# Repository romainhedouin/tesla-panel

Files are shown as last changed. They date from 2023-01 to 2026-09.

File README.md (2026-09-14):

# tesla-panel

Pi-side receiver for the 64×32 RGB LED matrix mounted in the car. Listens
over Bluetooth RFCOMM for commands from the
[TeslaLED](https://github.com/romainhedouin/TeslaLED) Android app and drives
the panel via [rpi-rgb-led-matrix](rpi-rgb-led-matrix/)'s Python bindings.

`rpi-rgb-led-matrix/` is a git submodule pointing straight at
[hzeller/rpi-rgb-led-matrix](https://github.com/hzeller/rpi-rgb-led-matrix)
(no local patches to carry - if that ever changes, fork it first rather
than patching the submodule in place). Clone this repo with `git clone
--recurse-submodules`, or run `git submodule update --init` afterwards if
you already cloned without it - `deploy.sh` needs it checked out locally
to have anything to rsync to the Pi.

`bt_server.py` is the entry point, wiring together `protocol.py` (the wire
protocol - hardware/transport agnostic, covered by `tests/`), `panel.py`
(the RGBMatrix hardware wrapper) and `bt_profile.py` (BlueZ D-Bus service
registration).

`esp32/` is an in-progress port to run instead of the Pi - see its own
README for status (compile-verified only, no hardware yet).

There is no CI/CD deploying to the Pi itself: `./deploy.sh` copies these files
onto the Pi's home directory (`/home/pi/`) by hand and restarts the systemd
service, but nothing runs that automatically - **a protocol or behavior
change isn't live until you actually run `./deploy.sh`**, and nothing checks
that the Pi is still in sync with what's committed here. `tests/` (`python3
-m pytest tests/`) only exercises `protocol.py`, so it catches wire-format
regressions but nothing hardware- or Bluetooth-related.

## Bill of materials

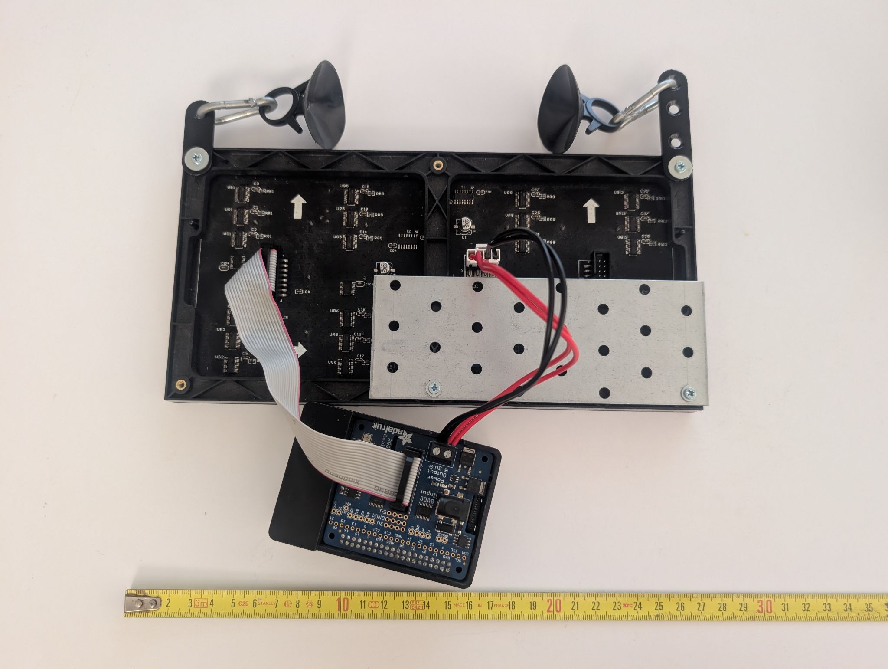
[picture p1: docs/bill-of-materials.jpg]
Panel back, mounting brackets, and HAT


- P4 indoor full-color RGB LED matrix module
  - [Reference photo](https://ae-pic-a1.aliexpress-media.com/kf/HTB1wbN2NVXXXXcDXVXXq6xXFXXX2.jpg) of the one used - no longer listed on AliExpress
  - [This listing](https://fr.aliexpress.com/i/32250605175.html?gatewayAdapt=glo2fra) looks similar but is unverified
- Raspberry Pi 3B+
  - A more recent Pi also works, but draws more power - a small fan may become necessary
- [Adafruit HUB75 HAT](https://www.amazon.fr/dp/B00SK69C6E?ref=ppx_yo2ov_dt_b_fed_asin_title)
- [Raspberry Pi 3/3B+ case](https://www.amazon.fr/dp/B09H6KR3JP?ref=ppx_yo2ov_dt_b_fed_asin_title)
  - Had to file off the plastic cover latches to fit the HAT
- [5.5x2.1mm power cable for the HAT](https://www.amazon.fr/dp/B07KFTPF4C?ref=ppx_yo2ov_dt_b_fed_asin_title)
  - Downsides: thin (22 AWG) and long (2m) - thinner/longer cables drop more
    voltage under load, risking under-voltage and visible brightness
    variability. Prefer shorter, thicker cables.
  - If buying today, would try [this one](https://www.amazon.fr/dp/B0FPKWNFLN/ref=sspa_dk_detail_5) instead - still 22 AWG and half the length, which is plenty
- Micro-USB cable for the Pi (USB-C on more recent models)
- M3 screws + washers
- Mounting brackets - the Tesla Model 3's rear window is laterally sloped
  - 2-hole bracket, 2.5cm between the external holes
  - 4-hole bracket, 4.5cm between the external holes
- 2 small carabiners, attached to the mounting brackets
- 2 small suction cups with a loop, attached to the carabiners
- 2-4 magnets, super-glued to the bottom of the Pi case
  - Mount onto the metal sheet below
- 6x16cm metal sheet with holes
  - Unclear original purpose - used here as an anchor point for the magnets
- A soldering iron, to solder the HAT onto the Pi
  - Easy job, just make sure to solder it the right way around or you'll
    have the delightful pleasure of learning to unsolder and re-solder all
    40 tiny little pins... ask how I know...

## Raspberry Pi OS install

Only needed once, on a fresh/replacement SD card, before `pi_side_install.sh`.
Use [Raspberry Pi Imager](https://www.raspberrypi.com/software/):

1. Choose **Raspberry Pi OS Lite (64-bit)** as the OS.
2. Choose the SD card as the storage device - **be very careful you've
   selected the right one**, this erases it.
3. Follow the app's setup prompts (hostname, user, SSH, WiFi, locale) and
   write.

## Wire protocol

`bt_server.py` speaks a length-prefixed binary protocol, matched byte-for-byte
by the Android app's `BluetoothClient`/`AGENTS.md`:

```
[1 byte command type][4 bytes big-endian payload length][payload]
```

followed by a response in the same shape, mirrored - `[1 byte status][4
bytes big-endian message length][message, UTF-8]`. `0x00` is OK (message
normally empty); anything else is an error, with the message carrying the
Pi's own explanation of what went wrong - the Android app surfaces that
text directly (e.g. as an "ERROR: ..." toast) instead of guessing at a
generic failure reason. Command types (kept in sync with the Android app's
constants of the same name):

| Command | Value | Payload |
|---|---|---|
| `COMMAND_IMAGE` | 0 | a 64×32 P6 PPM frame |
| `COMMAND_KILL` | 2 | none - clears the panel |
| `COMMAND_SET_BRIGHTNESS`  | 3 | 1 byte, 1-100 |

RFCOMM is a reliable ordered stream, so the length prefix is all that's
needed to find message boundaries - no sentinel value, no per-chunk acks.

Updates are flicker-free because `panel.py` creates the matrix and its
canvas once at startup and reuses them for the whole process - each command
does an atomic `SwapOnVSync` onto that same canvas, never a process
kill/respawn.

## Bluetooth service registration

`bt_profile.py` registers the RFCOMM service with BlueZ over D-Bus
(`org.bluez.ProfileManager1.RegisterProfile`) instead of PyBluez's
`advertise_service()` - see that file's module docstring for the full
reasoning. Short version: current BlueZ (5.82+, what Debian 13/trixie ships)
removed the legacy `/var/run/sdp` socket interface `advertise_service()`
(and `sdptool`) depend on, so both fail outright on this OS; and it has to
be a real SDP record, not a shortcut around one, because the Android app
connects via `createRfcommSocketToServiceRecord(UUID)`, which looks up the
RFCOMM channel through an actual SDP query at connect time. This also means
BlueZ owns the listening socket - it hands our exported `Profile1` an
already-connected fd per connection, so there's no `listen()`/`accept()`
anywhere in this codebase. Needs `python3-dbus` and `python3-gi` (installed
by `pi_side_install.sh`).

## Deployment

- Three systemd units (`conf/teslabot*.service`), each supervised
  independently via `Restart=always`:
  - `teslabot.service` runs `bt_server.py`.
  - `teslabot-agent.service` keeps a pairing agent
    (`bt-agent -c NoInputNoOutput`) registered.
  - `teslabot-discoverable.service` (a oneshot) powers Bluetooth on and makes
    it discoverable at boot; `/etc/bluetooth/main.conf`'s `DiscoverableTimeout
    = 0` (set by `pi_side_install.sh`) is what makes that stick instead of
    reverting after BlueZ's default 180s.
- Pairing a new phone with the Pi silently fails (no error anywhere, not even
  in `bluetoothctl paired-devices`) unless that pairing agent is running -
  if pairing won't complete, check `systemctl status teslabot-agent` before
  suspecting anything else.
- The Pi's Bluetooth MAC is hardcoded on the Android side
  (`BluetoothClient.findDevice()`); replacing the Pi means updating that
  constant and rebuilding the app.
- On a fresh Pi: `./deploy.sh` from this repo copies it onto the Pi, then
  `ssh teslapi` and run `./pi_side_install.sh` there (packages, compiling
  `rpi-rgb-led-matrix` and its Python bindings, installing the systemd units).
  Safe to re-run - most of its steps are no-ops if already done.
- After that first install, `./deploy.sh` alone is enough for routine code
  changes: it copies the repo over and restarts `teslabot.service`, so the
  new code is live immediately - no manual ssh/restart step needed.

## Troubleshooting

- **Colored static/noise instead of the actual image** is a GPIO-timing or
  wiring issue, not a protocol/software bug - reproduce it with the LED
  matrix library's own test patterns (`rpi-rgb-led-matrix/examples-api-use`)
  with no Bluetooth involved at all before looking anywhere else.
- **Pairing never completes**: see the pairing-agent note above.
- **Panel doesn't update / commands seem to hang**: check `bt_server.log` in
  `/home/pi/` and `journalctl -u teslabot` - a command whose handler raises
  gets logged and answered with an error status rather than silently
  dropped, so a hang usually means the client never got as far as sending
  the header/payload, not a wedged server.

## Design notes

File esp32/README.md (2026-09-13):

# ESP32 firmware (in progress)

Alternative to the Raspberry Pi, targeting the [HUB75 adapter for
ESP32-DevKitC V4 / ESP32-S3 DevKitC-1](https://www.amazon.fr/dp/B0FVGCF1RW).
Written and compile-verified with [PlatformIO](https://platformio.org/)
(`pip install platformio`) without the physical board in hand - `pio run`
only compiles/links, it doesn't need real hardware. **Nothing here has
been flashed to or tested on real hardware yet.**

## Why two environments

That adapter board is designed to take either dev board, and the two are
not interchangeable for our purposes: the original ESP32 has classic
Bluetooth (BR/EDR), the S3 dropped it entirely (BLE only). That's a
protocol-level fork, not a config option:

- **`esp32-classic`** (`src/main_classic.cpp`) - original ESP32. Uses
  Arduino's `BluetoothSerial` for RFCOMM/SPP, which registers the same
  standard SPP UUID (`00001101-...`) the Android app already targets via
  `createRfcommSocketToServiceRecord()` - no app-side changes needed to
  point it at this instead of the Pi.
- **`esp32-s3-ble`** (`src/main_ble.cpp`) - ESP32-S3. No classic Bluetooth
  radio exists on this chip, so this speaks BLE GATT instead: a custom
  service with a write characteristic (phone → board) and a notify
  characteristic (board → phone). **The Android app has no BLE client yet
  - this firmware alone doesn't make the S3 path usable end to end.**

`build_src_filter` in `platformio.ini` picks the right entry point per
environment; everything else (`protocol.h`, `panel.h`) is shared.

## Structure

- `protocol.h` - wire protocol, mirrors `protocol.py` at the repo root
  byte-for-byte (same command values, same length-prefixed framing, same
  response shape, same PPM parser). Transport-agnostic: only parses bytes
  already in a buffer, never touches Bluetooth directly.
- `panel.h` - HUB75 driving wrapper, mirrors `panel.py`'s role, built on
  [ESP32-HUB75-MatrixPanel-DMA](https://github.com/mrcodetastic/ESP32-HUB75-MatrixPanel-DMA)
  (confirmed to support ESP32/S2/S3). Double-buffered
  (`SwapOnVSync`-equivalent) for the same flicker-free updates as the Pi.
- `main_classic.cpp` / `main_ble.cpp` - the two entry points above.

## What's still unverified / unknown

- **Pin mapping**: left at the library's defaults - the adapter board's
  actual wiring isn't documented anywhere I could check without the
  hardware. Expect to adjust the `HUB75_I2S_CFG` in `panel.h` once it
  arrives.
- **Everything BLE-side is unverified beyond "it compiles"**: MTU
  negotiation, chunked reassembly under real radio conditions, actual
  throughput for a 6KB frame split into GATT writes - all need a real S3
  board and a real BLE central to know if the design holds up.
- **The Android BLE client doesn't exist yet** - see the custom UUIDs
  above; a separate, real piece of work.

## Building

```
cd esp32
pio run -e esp32-classic   # or -e esp32-s3-ble
pio run -e esp32-classic -t upload   # once you actually have the board wired up
```

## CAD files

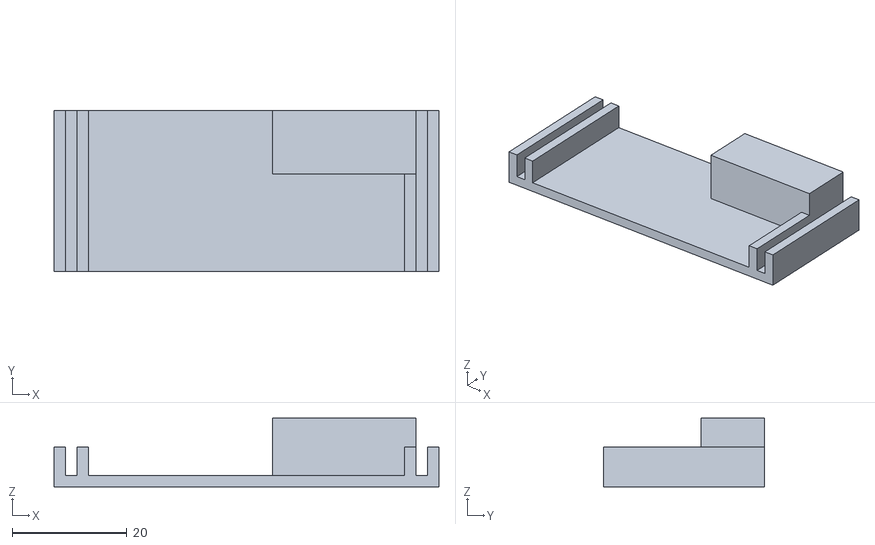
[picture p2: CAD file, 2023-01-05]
3d/box_closer.stl
67.0 x 28.0 x 12.0

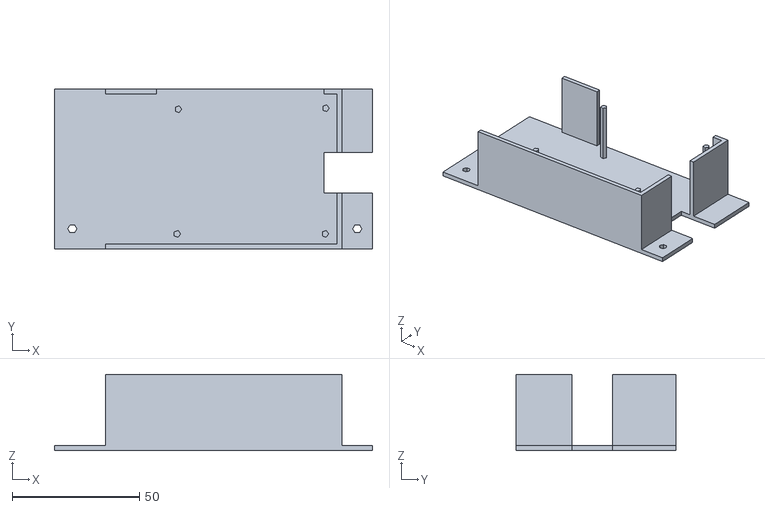
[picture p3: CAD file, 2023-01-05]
3d/box_bottom_v2_1.stl
125.0 x 63.0 x 30.0

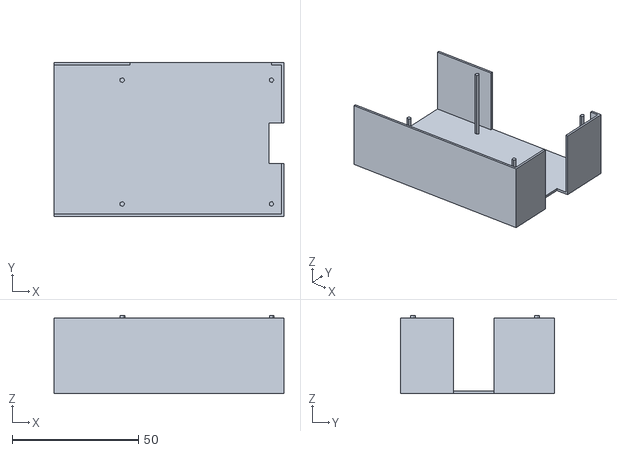
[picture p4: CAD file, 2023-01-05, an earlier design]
3d/box_bottom_v1.stl
91.0 x 61.0 x 31.0

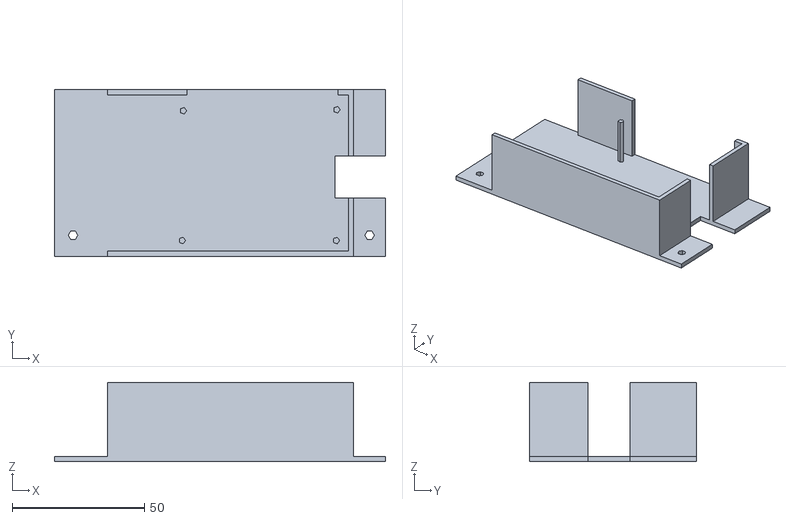
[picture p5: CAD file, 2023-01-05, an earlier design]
3d/box_bottom_v2.stl
125.0 x 63.0 x 30.0

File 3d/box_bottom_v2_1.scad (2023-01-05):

box_length=90;
box_width=59;
small_distance_between_holes=49;
box_height=30;
SD_side_grabber_length=15;
thickness=2;

// #translate([-2, 0, 27]) cube([1, 59, 1]);

//flat grabber
difference() {
    translate([-thickness, -thickness, -thickness])cube([box_length+SD_side_grabber_length, box_width+(thickness*2), thickness]);
    translate([84, 20, -5])cube([30, 16, 10]);
    translate([97, 6, -5]) cylinder(10, 1.8, 1.8);
}

difference () {
//grabber
    translate([-20-thickness, -thickness, -thickness]) cube([20, box_width+(thickness*2), thickness]);
    
    translate([-15, 6, -5]) cylinder(10, 1.8, 1.8);
}

// distance of 4 from right-most edge
// two sticks, close to closed side
translate([box_length - 5.6, 4, 0]) cylinder(26, 2.8/2, 2.8/2);
translate([box_length - 5.4, 53.4, 0]) cylinder(26, 2.8/2, 2.8/2);

// distance of 62 from right-most-edge
// two sticks, close to open side
translate([box_length - 63.8, 4, 0]) cylinder(26, 2.8/2, 2.8/2);
translate([box_length - 63.4, 53, 0]) cylinder(26, 2.8/2, 2.8/2);

// side support
translate([-thickness, -thickness, -thickness])cube([box_length + thickness, thickness, box_height]);
translate([84, box_width, -thickness])cube([5, thickness, box_height]);
translate([-thickness, box_width, -thickness])cube([20, thickness, box_height]);

difference() {
    translate([89, -thickness, -thickness]) cube([thickness, box_width+(2*thickness), box_height]);
    translate([88, 20, -10]) cube([thickness+2, 16, 50]);
}

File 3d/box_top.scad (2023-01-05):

thickness=2;
box_length=90;
box_width=59 + (thickness * 2 * 2);

// #translate([thickness*2, -2, 0]) cube([59, 1, 1]);

cube([box_width, 28, thickness]);
translate([0, 0, 1]) cube([thickness, 30-thickness, thickness*3]);
translate([thickness*2, 0, 1]) cube([thickness, 30-thickness, thickness*3]);

translate([box_width-thickness, 0, 1]) cube([thickness, 28, thickness*3]);
translate([box_width-(thickness*3), 0, 1]) cube([thickness, 28, thickness*3]);

translate([box_width - (thickness * 3) - 23, 17, thickness]) cube([23+thickness, 11, 10]);

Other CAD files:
3d/box_bottom_v1.scad
3d/box_bottom_v2.scad

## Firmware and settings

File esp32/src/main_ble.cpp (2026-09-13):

// Entry point for the ESP32-S3 (BLE only - no classic Bluetooth radio at
// all on this chip, so BluetoothSerial/SPP isn't an option here). Speaks
// the same logical wire protocol as the Pi/classic-ESP32 (protocol.h), but
// framed differently: BLE GATT writes/notifies are capped by the
// negotiated MTU (a handful of hundred bytes at best), while a 64x32 PPM
// image is ~6.2KB - the phone must split a command across several
// characteristic writes, and this reassembles them here before dispatching.
//
// Custom GATT service (no standard profile fits this - unlike classic SPP,
// BLE has no generic "serial port" analog):
//   Service:               c9af0000-1a1a-4e7e-9a1e-4b1e2f6a9c00
//   Command characteristic c9af0000-1a1a-4e7e-9a1e-4b1e2f6a9c01 (write)  - phone -> board
//   Response characteristic c9af0000-1a1a-4e7e-9a1e-4b1e2f6a9c02 (notify) - board -> phone
// The Android app needs a BLE client implementing this service to talk to
// this firmware variant - a separate piece of work from this firmware.
#include <Arduino.h>
#include <BLE2902.h>
#include <BLEDevice.h>
#include <BLEServer.h>
#include <BLEUtils.h>

#include <vector>

#include "panel.h"
#include "protocol.h"

namespace {

constexpr char kServiceUuid[] = "c9af0000-1a1a-4e7e-9a1e-4b1e2f6a9c00";
constexpr char kCommandCharUuid[] = "c9af0000-1a1a-4e7e-9a1e-4b1e2f6a9c01";
constexpr char kResponseCharUuid[] = "c9af0000-1a1a-4e7e-9a1e-4b1e2f6a9c02";

Panel *gPanel;
BLEServer *gServer;
BLECharacteristic *gResponseChar;

// Growable reassembly buffer for the command currently being received -
// BLE writes arrive in MTU-sized chunks (a fraction of a 6KB image frame),
// so a full command is spread across several onWrite() calls. Reset once
// a full command has been dispatched, or when a new connection begins.
std::vector<uint8_t> gBuffer;

void sendResponse(uint8_t status, const String &message) {
  uint8_t header[protocol::RESPONSE_HEADER_SIZE];
  header[0] = status;
  protocol::writeU32BE(header + 1, message.length());
  // Response is always small (a short status message) - well under any
  // negotiated MTU, so unlike the command direction this never needs to be
  // split across multiple notifications.
  std::vector<uint8_t> response(header, header + sizeof(header));
  response.insert(response.end(), message.begin(), message.end());
  gResponseChar->setValue(response.data(), response.size());
  gResponseChar->notify();
}

// Dispatches the fully-reassembled command in gBuffer, mirroring
// handle_one_command() in protocol.py, then clears it for the next one.
void dispatchBufferedCommand() {
  protocol::ParsedHeader parsed = protocol::parseHeader(gBuffer.data());
  const uint8_t *payload = gBuffer.data() + protocol::HEADER_SIZE;

  String error;
  bool ok;
  switch (parsed.commandType) {
    case protocol::COMMAND_IMAGE:
      ok = gPanel->handleImage(payload, parsed.length, &error);
      break;
    case protocol::COMMAND_KILL:
      ok = gPanel->handleKill(&error);
      break;
    case protocol::COMMAND_SET_BRIGHTNESS:
      ok = gPanel->handleSetBrightness(payload, parsed.length, &error);
      break;
    default:
      ok = false;
      error = "Unknown command type: " + String(parsed.commandType);
      break;
  }

  if (ok) {
    sendResponse(protocol::STATUS_OK, "");
  } else {
    Serial.println("[-] Command " + String(parsed.commandType) + " failed: " + error);
    sendResponse(protocol::STATUS_ERROR, error);
  }
  gBuffer.clear();
}

class CommandCallbacks : public BLECharacteristicCallbacks {
  void onWrite(BLECharacteristic *characteristic) override {
    uint8_t *data = characteristic->getData();
    size_t length = characteristic->getLength();
    gBuffer.insert(gBuffer.end(), data, data + length);

    if (gBuffer.size() < protocol::HEADER_SIZE) {
      return;  // haven't even got the header yet
    }
    protocol::ParsedHeader parsed = protocol::parseHeader(gBuffer.data());
    if (parsed.length > protocol::MAX_PAYLOAD_SIZE) {
      Serial.printf("[-] Payload length %u exceeds max %u (desynced stream?) - resetting\n",
                    (unsigned)parsed.length, (unsigned)protocol::MAX_PAYLOAD_SIZE);
      gBuffer.clear();
      return;
    }
    if (gBuffer.size() >= protocol::HEADER_SIZE + parsed.length) {
      dispatchBufferedCommand();
    }
  }
};

class ServerCallbacks : public BLEServerCallbacks {
  void onConnect(BLEServer *server) override {
    Serial.println("[+] BLE client connected");
    gBuffer.clear();
  }

  void onDisconnect(BLEServer *server) override {
    Serial.println("[+] BLE client disconnected");
    gBuffer.clear();
    // Arduino BLE doesn't resume advertising on its own after a disconnect.
    server->startAdvertising();
  }
};

}  // namespace

void setup() {
  Serial.begin(115200);
  gPanel = new Panel();
  gBuffer.reserve(protocol::HEADER_SIZE + 4096);

  BLEDevice::init("teslapi-esp32-ble");
  BLEDevice::setMTU(517);  // request the max - fewer chunks per image frame

  gServer = BLEDevice::createServer();
  gServer->setCallbacks(new ServerCallbacks());

  BLEService *service = gServer->createService(kServiceUuid);

  BLECharacteristic *commandChar = service->createCharacteristic(
      kCommandCharUuid, BLECharacteristic::PROPERTY_WRITE | BLECharacteristic::PROPERTY_WRITE_NR);
  commandChar->setCallbacks(new CommandCallbacks());

  gResponseChar = service->createCharacteristic(kResponseCharUuid, BLECharacteristic::PROPERTY_NOTIFY);
  gResponseChar->addDescriptor(new BLE2902());  // CCCD - required for the client to enable notifications

  service->start();
  gServer->getAdvertising()->addServiceUUID(kServiceUuid);
  gServer->getAdvertising()->start();
  Serial.println("[+] BLE GATT server started as \"teslapi-esp32-ble\"");
}

void loop() {
  delay(100);  // everything happens in BLE callbacks - nothing to poll here
}

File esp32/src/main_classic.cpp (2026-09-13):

// Entry point for the original ESP32 (classic Bluetooth/BR-EDR). Speaks
// the exact same RFCOMM/SPP protocol as the Pi (bt_server.py/protocol.py):
// BluetoothSerial registers the standard SPP UUID
// (00001101-0000-1000-8000-00805F9B34FB) automatically, the same one the
// Android app already targets via createRfcommSocketToServiceRecord() -
// no app-side changes needed to talk to this instead of the Pi.
//
// Mirrors bt_server.py/protocol.py's blocking-read design directly:
// BluetoothSerial extends Arduino's Stream, so the same recv_exact()-style
// loop works here almost unchanged, just reading from SerialBT instead of
// a Python socket.
#include <Arduino.h>
#include <BluetoothSerial.h>

#include "panel.h"
#include "protocol.h"

#if !defined(CONFIG_BT_ENABLED) || !defined(CONFIG_BT_SPP_ENABLED)
#error Bluetooth Classic/SPP is not enabled in this build's sdkconfig - \
       needed by BluetoothSerial. See the espressif32 platform docs for \
       enabling CONFIG_BT_SPP_ENABLED.
#endif

namespace {

BluetoothSerial gSerialBT;
Panel *gPanel;

// Reads exactly n bytes from the connected client, blocking - mirrors
// recv_exact() in protocol.py. Returns false if the connection drops.
bool recvExact(uint8_t *buf, size_t n) {
  size_t total = 0;
  while (total < n) {
    if (!gSerialBT.hasClient()) {
      return false;
    }
    int avail = gSerialBT.available();
    if (avail <= 0) {
      delay(1);
      continue;
    }
    int got = gSerialBT.readBytes(buf + total, min(size_t(avail), n - total));
    if (got <= 0) {
      return false;
    }
    total += got;
  }
  return true;
}

void sendResponse(uint8_t status, const String &message) {
  uint8_t header[protocol::RESPONSE_HEADER_SIZE];
  header[0] = status;
  protocol::writeU32BE(header + 1, message.length());
  gSerialBT.write(header, sizeof(header));
  if (message.length() > 0) {
    gSerialBT.write((const uint8_t *)message.c_str(), message.length());
  }
}

// Reads and dispatches a single command - mirrors handle_one_command() in
// protocol.py. Returns false once the client has disconnected.
bool handleOneCommand() {
  uint8_t header[protocol::HEADER_SIZE];
  if (!recvExact(header, sizeof(header))) {
    return false;
  }
  protocol::ParsedHeader parsed = protocol::parseHeader(header);

  if (parsed.length > protocol::MAX_PAYLOAD_SIZE) {
    Serial.printf("[-] Payload length %u exceeds max %u (desynced stream?) - dropping connection\n",
                  (unsigned)parsed.length, (unsigned)protocol::MAX_PAYLOAD_SIZE);
    return false;
  }

  // Static, not stack-allocated: the default Arduino loop task stack is
  // only 8KB, far too small for a 64KB buffer.
  static uint8_t payload[protocol::MAX_PAYLOAD_SIZE];
  if (parsed.length > 0 && !recvExact(payload, parsed.length)) {
    return false;
  }

  String error;
  bool ok;
  switch (parsed.commandType) {
    case protocol::COMMAND_IMAGE:
      ok = gPanel->handleImage(payload, parsed.length, &error);
      break;
    case protocol::COMMAND_KILL:
      ok = gPanel->handleKill(&error);
      break;
    case protocol::COMMAND_SET_BRIGHTNESS:
      ok = gPanel->handleSetBrightness(payload, parsed.length, &error);
      break;
    default:
      ok = false;
      error = "Unknown command type: " + String(parsed.commandType);
      break;
  }

  if (ok) {
    sendResponse(protocol::STATUS_OK, "");
  } else {
    Serial.println("[-] Command " + String(parsed.commandType) + " failed: " + error);
    sendResponse(protocol::STATUS_ERROR, error);
  }
  return true;
}

}  // namespace

void setup() {
  Serial.begin(115200);
  gPanel = new Panel();
  gSerialBT.begin("teslapi-esp32");
  Serial.println("[+] Bluetooth SPP server started as \"teslapi-esp32\"");
}

void loop() {
  if (gSerialBT.hasClient()) {
    while (handleOneCommand()) {
    }
    Serial.println("[+] Disconnected");
  }
  delay(10);
}

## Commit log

2022-07-14 creating project
    [active3-rpi-hub75-adapter.kicad_pcb, active3-rpi-hub75-adapter.sch, passive-rpi-hub75-adapter.kicad_pcb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]
2023-01-05 architecture switched to bluetooth
    [box_bottom_v1.scad, box_bottom_v1.stl, box_bottom_v2.scad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]
2023-01-07 functional Python server prototype for Java client prototype
2023-01-08 updating rpi-rgb-led-matrix
2023-01-08 resetting rpi-rgb-led-matrix
    [active3-rpi-hub75-adapter.kicad_pcb, active3-rpi-hub75-adapter.sch, passive-rpi-hub75-adapter.kicad_pcb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]
2023-01-10 switching to new 2-step command system
2023-01-11 print->logger prepared image command while keeping legacy commands working
2026-09-07 Sync bt_server.py/teslabot/systemd unit with what's actually deployed on the Pi
    The committed bt_server.py still had the old ad-hoc DONE-sentinel protocol;
    the Pi had been running a length-prefixed COMMAND_IMAGE/COMMAND_KILL/
    COMMAND_SET_BRIGHTNESS version driving rpi-rgb-led-matrix's Python bindings
    directly (flicker-free SwapOnVSync) for a while, never pushed back here.
    teslabot also gained a pairing-agent loop (bt-agent) and the systemd unit
    changed (User=pi, Wants=bluetooth.target) - both pulled in to match.
    pi_side_install.sh gets the matching new steps (bluez-tools package,
    building/installing the Python bindings) merged into the existing bootstrap
    rather than replaced outright, since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
    [bt_server.py]
2026-09-12 Document Raspberry Pi OS install steps in README
    Points to Raspberry Pi Imager for flashing a fresh/replacement SD card,
    since the existing docs assumed the OS was already installed.
2026-09-12 Fix Pi OS install for Debian 13/Python 3.13, drop emacs, split deploy from install
    Three real bugs found by actually running the install end-to-end on a
    freshly flashed Pi: a broken sudoers bootstrap (sudo echo >> silently
    no-ops), a dead wpa_supplicant.conf step (WiFi is already configured by
    Raspberry Pi Imager via NetworkManager/netplan), and distutils removal
    in Python 3.13 breaking rpi-rgb-led-matrix's Python bindings setup.py.
    Also regenerates the bindings' Cython output (core.cpp/graphics.cpp) at
    install time instead of committing it - the committed version was built
    against an old Cython/CPython ABI and silently stopped compiling once
    this Pi's Python removed the internals it poked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
2026-09-12 Replace PyBluez SDP registration with BlueZ D-Bus Profile1, verified against the real Android app
    bt_server.py's advertise_service() call (PyBluez) failed unconditionally
    with ENOENT on this BlueZ version (5.82, current on Debian 13/trixie) -
    confirmed the legacy /var/run/sdp socket interface it and sdptool depend
    on has been removed entirely, not just misconfigured. This isn't
    cosmetic: the real Android app connects via
    createRfcommSocketToServiceRecord(UUID), which performs a live SDP query
    at connect time, so a fixed-channel workaround (fine for this repo's own
    bt_client.py test script) would not have satisfied the actual app.
    bt_profile.py registers the RFCOMM/SPP service through
    org.bl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
    [bt_profile.py, bt_server.py, panel.py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]
2026-09-12 Update vendored rpi-rgb-led-matrix to current upstream (hzeller/master)
    Last synced 2021-03-05 - 506 commits/5.5 years behind. Upstream replaced
    the old setup.py/cythonize-by-hand Python bindings build with a
    CMakeLists.txt driven by scikit-build-core (pyproject.toml), which also
    obsoletes the 3 manual Cython/Python-3.13 compatibility patches applied
    a few days ago (setup.py, core.pyx, core.pxd): upstream's current
    core.pyx/core.pxd use a different, non-name-mangled method pattern that
    doesn't hit the same Cython 3.x strictness issues.
    Verified before pulling: panel.py's RGBMatrixOptions usage (rows, cols,
    chain_length, parallel, hardware_mapping, gpio_slowdown,
    disable_hardware_pulsing, br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
    [active3-rpi-hub75-adapter.kicad_pcb, active3-rpi-hub75-adapter.sch, passive-rpi-hub75-adapter.kicad_pcb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]
2026-09-12 Convert vendored rpi-rgb-led-matrix into a git submodule
    Replaces 235 tracked files (a plain copy-paste vendor drop) with a single
    gitlink pinned at hzeller/rpi-rgb-led-matrix's current master - future
    upstream updates become a one-line pointer bump instead of a wholesale
    directory swap that drowns out tesla-panel's own history.
    No personal fork needed for this: we carry zero local patches against
    upstream right now (confirmed working as-is on the Pi), and forking only
    earns its keep once there's something of ours to carry on top of it.
    [active3-rpi-hub75-adapter.kicad_pcb, active3-rpi-hub75-adapter.sch, passive-rpi-hub75-adapter.kicad_pcb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]
2026-09-12 Remove the C/C++ CI workflow - dead, tests nothing relevant here
    It ran bare `make` at the repo root, but rpi-rgb-led-matrix (where the
    actual Makefile lives) has been a subdirectory for years and is now a
    submodule this workflow's checkout doesn't even fetch - it's failed on
    every push. Building/testing that library is upstream's job in their
    own CI; this repo just consumes it via pip on the Pi. python-tests.yml
    already covers what's actually ours (the wire protocol).
2026-09-12 Reject an oversized payload length instead of crashing on it
    Root-caused a real production freeze: a Bluetooth HCI UART transport
    error ("bad checksum in packet" / "Frame reassembly failed (-84)" in
    dmesg, correlated to this Pi's confirmed active under-voltage condition)
    corrupted a command header mid-stream. recv_exact() trusted the garbage
    ~4GB length it decoded and called sock.recv() with it, which the kernel's
    own memory-overcommit guard rejected - surfacing as an uncaught
    MemoryError that killed the connection's handler thread without closing
    the socket. The Android app kept writing to that now-unread socket and
    blocking on the ack that would never arrive, wedging the whole app until
    fo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
    [protocol.py]
2026-09-12 Trim README duplication with bt_profile.py/panel.py docstrings
    The Bluetooth service registration and wire protocol sections restated
    those files' own module/inline comments almost verbatim. Condensed to
    the headline reasoning and deferred to the source for the rest, rather
    than maintaining the same explanation in two places.
2026-09-12 Add power tuning to pi_side_install.sh: disable unused audio/camera/display, prompt for eth0
    This Pi is headless in a car - HDMI/camera/DSI are never connected and
    nothing uses onboard audio. Disable those outright (idempotent config.txt
    edits, safe to re-run). Skipped disabling HDMI itself: verified that on
    Bookworm/Trixie's vc4-kms-v3d driver, a headless boot with no display
    ever connected already never powers the HDMI transceiver on in the first
    place, and there's no confirmed-working config.txt directive left to
    force it off regardless (hdmi_blanking=2 is undocumented/unsupported
    here, tvservice/vcgencmd display_power are both dead on this driver).
    eth0 is prompted for rather than auto-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
2026-09-12 Carry real error messages in the response, not just an opaque status byte
    The Android app's Connected/Not connected/Displaying status was already
    based on a genuine round-trip from the Pi (STATUS_OK only follows a
    successful handler run) - but a failure was a single ambiguous byte, so
    the app could never say what actually went wrong, only "failed."
    Response is now [1 byte status][4 bytes big-endian length][message,
    UTF-8], mirroring the request framing. STATUS_ERROR now carries the
    Pi's own explanation: which command was unrecognized, the exact
    handler exception message (invalid brightness value, malformed PPM
    data), etc. parse_ppm's bare `assert data[0:2] == b"P6"` became a real
    ValueError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
    [protocol.py]
2026-09-13 Add bill of materials section with photo of the mounting hardware
2026-09-13 Note soldering iron requirement and cable length/voltage tradeoff in BOM
2026-09-13 Add current recommended replacement for the HAT power cable
2026-09-13 Clarify recommended replacement HAT power cable is 22 AWG, half the length
2026-09-13 Wording tweak in BOM cable note
2026-09-13 Add in-progress ESP32 port (compile-verified, not yet flashed to hardware)
    New esp32/ PlatformIO project targeting the HUB75 adapter that takes
    either an original ESP32-DevKitC V4 or an ESP32-S3 DevKitC-1 - two build
    environments since that's a real protocol fork, not a config option:
    the original ESP32 has classic Bluetooth (BR/EDR), the S3 dropped it
    entirely for BLE-only.
    - protocol.h: C++ mirror of protocol.py, byte-for-byte identical wire
    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
2026-09-14 Add BLE GATT peripheral on the Pi for testing TeslaLED's BleTransport
    Runs alongside the existing classic SPP profile, not instead of it, so the
    Android app's BLE transport can be built and verified against real hardware
    before the ESP32-S3 exists. Registration must happen after the GLib mainloop
    starts pumping and use the async reply_handler/error_handler pattern -
    BlueZ's RegisterApplication() calls back into this process to walk the
    service tree, which deadlocks if done synchronously or before the mainloop
    is running.
    [bt_ble.py, bt_server.py]
2026-09-14 Clean up prototype-era leftovers; DRY BlueZ registration retry constants
    bt_server.py's pid-file kill logic never fired (nothing wrote that file) -
    a holdover from the pre-systemd supervisor. bt_client.py and src/*.sh were
    disconnected prototype scripts predating the Bluetooth-driven protocol,
    already superseded once kill/sleep moved to the Android app. bt_profile.py
    and bt_ble.py each retry BlueZ registration at boot with their own copy of
    the same delay/attempt constants and log message shape - factored into
    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
